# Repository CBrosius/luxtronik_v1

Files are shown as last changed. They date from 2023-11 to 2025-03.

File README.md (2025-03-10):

# luxtronik_v1 for Home Assistant
Luxtronik_v1 ESPHome External Component

# English version
This is a ESPHome ExternalComponent, that is able to read values from a Alpha Innotec Luxtronic_v1 Heatpump via Serial Connection (RS232)
and send the values to Homeassistant via Homeassistant-API or to other Smarthome Systems via MQTT

HowTo:
1. Edit luxtronik_v1.yaml according to your needs
3. Compile and Upload to your Sensor

# German Version
Mit einem ESP wird eine serielle Verbindung zur Luxtronik v1 Wärmepumpensteuerung hergestellt, es werden Werte ausgelesen und über die ESPHOME API für Home Assistant oder über MQTT für andere Smarthome Systeme bereitgestellt.

## Voraussetzungen

### Software
- Python [Anleitung](https://esphome.io/guides/installing_esphome)
- ESPHome Installation --> [download](https://esphome.io/)

### Hardware
- ESP (empfohlen ESP32)
- MAX3232-Modul
- serielles Kabel
- Sub-D9 Stecker männlich

## Serielle Verbindung
Die größte Hürde in diesem Projekt stellt die serielle Verbindung von der Luxtronik v1 zum ESP dar. Dieser Schritt wird die meiste Zeit in der Umsetzung erfordern.
Die Luxtronik verwendet 5V Pegel, während der ESP 3,3V Pegel verwendet, daher braucht es das MAX3232-Modul. Von allen möglichen Belegungen bei einem seriellen Kabel funktioniert letztlich nur eine, hier RX, TX und Ground/GND/Erde.

### ESP an MAX3232
Eine direkte Verbindung des ESP mit der Luxtronik v1 ist wegen der unterschiedlichen Spannungen nicht erfolgreich. Daher werden die PINs aus der ESP-Konfiguration mit dem MAX3232 verbunden. 

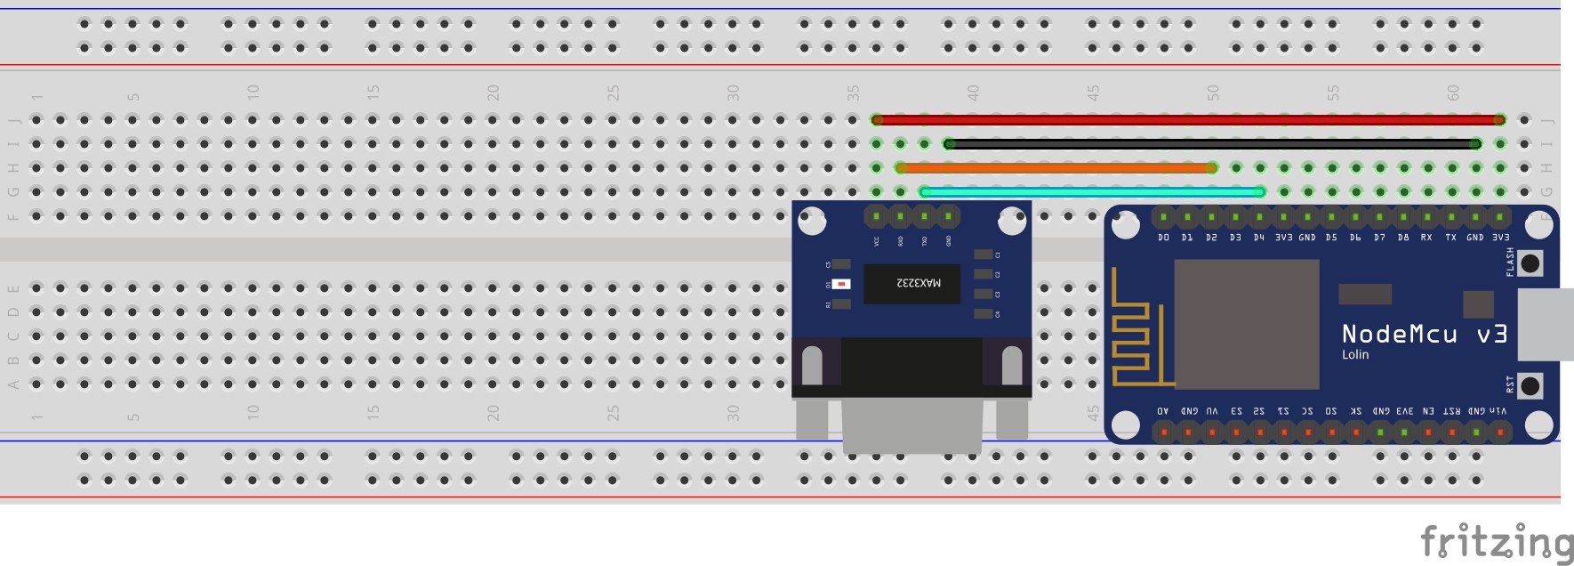
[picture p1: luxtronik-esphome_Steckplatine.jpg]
luxtronik-esphome_Steckplatine

#### D1 Mini
- ESP PIN D5 an MAX3232 RX
- ESP PIN D6 an MAX3232 TX
- ESP 3,3V an MAX3232 VCC
- ESP G an MAX3232 GND

#### ESP32
- ESP 3,3V an MAX3232 VCC
- ESP GND an MAX3232 GND
- ESP PIN RX2 (GPIO16) an MAX3232 RX 
- ESP PIN TX2 (GPIO17) an MAX3232 TX

### Serielles Kabel
Das serielle Kabel muss an der Luxtronik Platine angeschlossen werden. Dort gibt es einen männlichen Steckeranschluss (male), entsprechend muss das Kabel hier Buchsen (female) haben. Das MAX3232-Modul hat einen weiblichen Sub-D9 Buchsenanschluss (female), entsprechend braucht das Kabel hier einen männlichen Stecker (male). Kurz das Kabel braucht an einem Ende einen männlichen/male und am anderen Ende einen weiblichen/female Sub-D9 Stecker. Solche Kabel mit richtiger Belegung sind schwer zu finden, daher basteln wir uns ein solches Kabel selbst.

**Hinweis** Kommt keine serielle Verbindung zu stande, empfiehlt es sich an einer Seite RX und TX zu testweise zu tauschen.

#### Allgemeine RS232 Belegung
Das serielle Kabel muss wie folgt belegt sein:
- Pin 2 = RX
- Pin 3 = TX
- Pin 5 = GND / Erde

Beim Blick auf den Stecker bzw. die Buchse sind die Pins bei Buchse und Stecker an unterschiedlichen Stellen. Bei der Buchse sind die Pins 1- 5 die obere/breite Reihe von links nach rechts, beim Stecker von rechts nach links.

**Hinweis** Einen Genderchanger - also ein Zwischenstecker, der z.B. aus einer weiblichen Buchse einen männlichen Stecker macht - setzt man ein, wenn man z.B. nur zwei weibliche Stecker zur Verfügung hat. Dieser Genderchanger tauscht üblicherweise RX & TX. Wenn du einen Genderchanger einsetzt, musst du das bei der Belegung des Kabels beachten (und TX/RX tauschen, damit dann trotzdem 1:1 herauskommt).

#### Variante lötfreies Kabel
Die vorhandenen seriellen Kabel habe oft sehr dünne Litzen und sind entsprechend sensibel, was Zugbelastungen angeht. Möglicherweise möchtest du den ESP einige Meter entfernt von der Wärmepumpe betreiben, weil dort der WLAN-Empfang besser ist und brauchst daher eine entsprechend langes serielles Kabel.
Der Vorteil dieser Variante ist, dass als Kabel "Klingeldraht" verwendet werden kann und nicht gelötet werden muss.
Materialliste:
- dreiadriges Kabel in gewünschter Länge
- Sub-D9-Stecker lötfrei [Internetsuche](https://www.google.com/search?q=breakout+db9+connector+male)
- Sub-D9-Buchse lötfrei [Internetsuche](https://www.google.com/search?q=breakout+db9+connector+female)

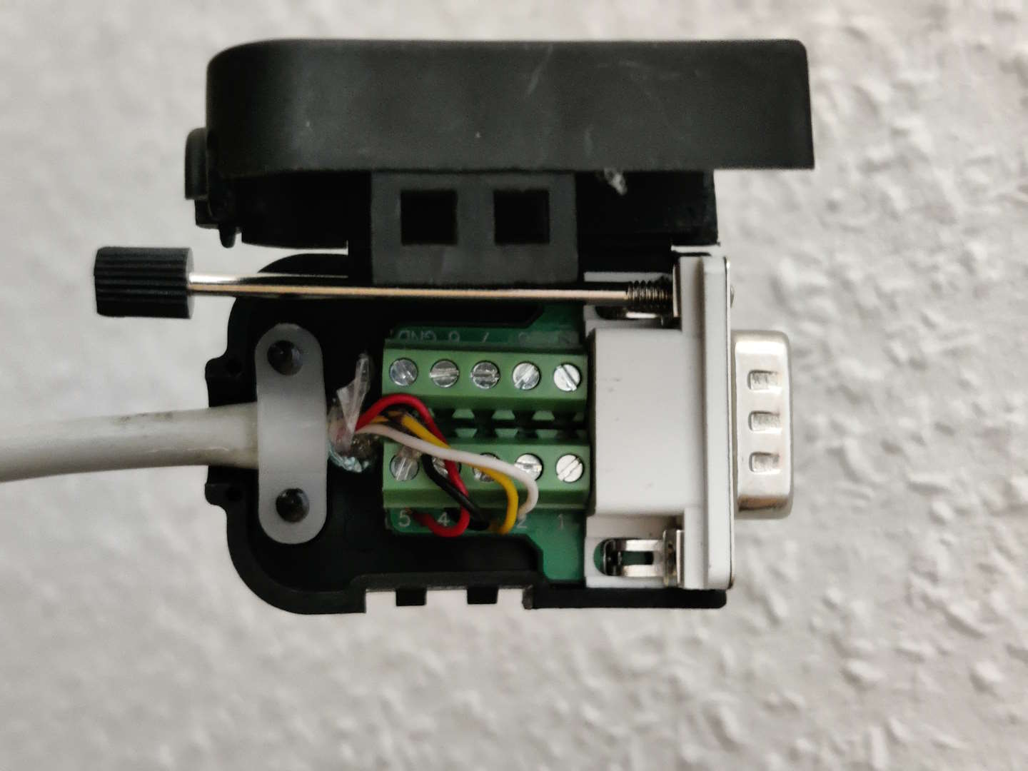
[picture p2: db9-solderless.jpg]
Db9-Lötfrei


#### Variante Cisco Konsolkabel
Ausgangspunkt ist ein Cisco Konsolkabel Sub-D9 auf RJ45, wie es für die Konfiguration von Netzwerkkomponenten des Herstellers zum Einsatz kommt - das ist kein MUSS, es funktioniert auch mit jedem beliebigen anderen Kabel.
Vom Sub-D9-Stecker werden von nur die PINs ??5 (RX), 6 (TX) und 4 (GND) benötigt. Diese haben folgende Kabelfarben:
- SubD9-PIN2, TX = rot
- SubD9-PIN3, RX = grün
- SubD9-PIN4, GND = gelb (auch PIN5 ist GND = orange) ??müsste es nicht PIN5/orange sein?

siehe auch: [hier](https://www.cable-tester.com/rj45-rs232-console-cable-pin-out/)
Schneide den RJ45-Stecker ab und löte den separten, männlichen Sub-D9-Stecker wie folgt an:
- grünes Kabel an SubD9-PIN 2 (TX)
- rotes Kabel an SubD9-PIN 3 (RX)
- gelbes Kabel an SubD9-PIN 5 (GND)

Info: Belegung von [Sub-D9](https://www.cable-tester.com/rs232-pin-out/).
### Luxtronik v1 Wartungszugang freischalten
An deiner Wärmepumpe gehe unter *Einstellungen, Datenzugang* dort die PIN 9445 für den Kundendienstzugang eingeben und bestätigen. Es passiert erstmal nix, es sind jetzt aber weitere Menüs erreichbar. Jetzt unter *Einstellungen, Diagnose* Standard auswählen. Damit ist die serielle Schnittstelle freigegeben. 

### secrets.yaml anlegen
Du brauchst eine Datei secrets.yaml in der du insbesondere die Werte für das WLAN einträgst:
```
# Your Wi-Fi SSID and password
wifi_ssid: "<SSID>"
wifi_password: "<WPA-Key>"
```
Wenn du die Home Assistant für die Erstellung von ESPHOME verwendest, dann hast du wahrscheinlich schon eine passende secrets.yaml.

Alle anderen Werte solltest du nur ändern, wenn du weißt, was du tust.

### ESPHome

#### Home Assistant Add-on 
Sofern noch nicht geschehen installierst du das Add-on "ESPHOME" (Einstellungen, Add-ons, Add-on-Store).

Wechsel in die "Benutzeroberfläche" von ESPHOME (z.B. über Einstellungen, Add-ons, ESPHOME, Benutzeroberfläche öffnen). Dort erscheint nun der "luxtronik-v1-esp32". Bei der erstmaligen Installation muss du ihn per Micro-USB an den PC anschließen und einen geeigneten Browser verwenden, um den Scetch auf den ESP zu laden. Weitere Updates können via WLAN erfolgen.

#### Windows
ESPHome ist eine Konsolenanwendung (unter Linux wie unter Windows).
Du kopierst alle Dateien des Projektes und deine secrets.yaml in das Hauptverzeichnis von esphome unter Windows standardmäßig c:\Users\\deinName\\.

Hinweis: Weitere Informationen findest du unter [esphome.io](https://esphome.io/guides/getting_started_command_line)

Stelle eine serielle Verbindung des ESP zum PC her. Das geht am einfachsten mit einem NodeMCU-Board, in diesem Fall schließe den ESP per Micro-USB-Kabel an deinen PC an. Es wird ein serieller Port am PC erzeugt (COM-Port, z.B. COM3).

Öffne eine Konsole, unter Windows öffne "command" und gib `esphome run luxtronik_v1-esp32.yaml` ein. Jetzt wird der Scetch compiliert, beim ersten mal dauert das ein paar Minuten.
Am Ende musst du auswählen, wie die Binärdatei auf den ESP kommt. Beim ersten Durchlauf musst du die serielle Verbindung nutzen, weitere Änderungen kannst du "OTA" (over the air) über das WLAN auf den ESP bringen, wenn dieser online ist.

#### WebInterface
Du kannst das WebInterface des ESP aufrufen und wirst die Werte der Luxtronik sehen können. 
Die IP-Adresse findest in deinem Router/DHCP-Server oder direkt im LOG des ESPHome-Devices.

## weitere Quellen
- https://wiki.fhem.de/wiki/Luxtronik_1_in_FHEM
- https://homematic-forum.de/forum/viewtopic.php?t=38814 
- https://knx-user-forum.de/forum/%C3%B6ffentlicher-bereich/knx-eib-forum/38901-%E2%88%9A-alpha-innotec-luxtronic-serielle-verbindung 
- http://www.hoerndlein.de/cms/index.php/openhab/8-einbindung-der-luxtronik-1-in-openhab
- https://bitbucket.org/tobylorenz/ait_luxtronik/src/master/
- https://www.haustechnikdialog.de/Forum/t/82258/Alpha-InnoTec-Anschluss-am-PC-klappt-nicht?page=23

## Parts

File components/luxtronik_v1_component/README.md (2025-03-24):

```yaml
# example configuration:

esphome:
  name: luxtronik-test
  friendly_name: luxtronik-test

esp32:
  board: esp32dev
  framework:
    type: esp-idf

wifi:
  ssid: !secret wifi_ssid
  password: !secret wifi_password
  fast_connect: True

# Enable logging
logger:
  # disable serial loggin
  baud_rate: 0

web_server:

api:

ota:
  platform: esphome

uart:
  id: uart_bus
  rx_pin: GPIO2
  tx_pin: GPIO4
  baud_rate: 57600
  data_bits: 8
  parity: NONE
  stop_bits: 1
#  debug:
#    direction: BOTH
#    dummy_receiver: false

external_components:
  - source:
      type: git
      url: https://github.com/cbrosius/luxtronik-v1-component
      ref: Input-sensors
    components: [ luxtronik_v1_component ]
    refresh: 0s

luxtronik_v1_component:
  id: luxtronik_v1_component_1
  temperatur_vorlauf:
    name: "Temperatur Vorlauf"
    id: temperatur_vorlauf
  temperatur_ruecklauf:
    name: "Temperatur Rücklauf"
    id: temperatur_ruecklauf
  temperatur_ruecklauf_soll:
    name: "Temperatur Rücklauf Soll"
    id: temperatur_ruecklauf_soll
  temperatur_heissgas:
    name: "Temperatur Heissgas"
    id: temperatur_heissgas
  temperatur_aussen:
    name: "Temperatur Aussen"
    id: temperatur_aussen
  temperatur_brauchwasser:
    name: "Temperatur Brauchwasser"
    id: temperatur_brauchwasser
  temperatur_brauchwasser_soll:
    name: "Temperatur Brauchwasser Soll"
    id: temperatur_brauchwasser_soll
  temperatur_waermequelle_eingang:
    name: "Temperatur Wärmequelle Eingang"
    id: temperatur_waermequelle_eingang
  temperatur_kaeltekreis:
    name: "Temperatur Kältekreis"
    id: temperatur_kaeltekreis
  temperatur_mischkreis1_vorlauf:
    name: "Temperatur Mischkreis1 Vorlauf"
    id: temperatur_mischkreis1_vorlauf
  temperatur_mischkreis1_vorlauf_soll:
    name: "Temperatur Mischkreis1 Vorlauf Soll"
    id: temperatur_mischkreis1_vorlauf_soll
  temperatur_raumstation:
    name: "Temperatur Raumstation"
    id: temperatur_raumstation
  eingang_abtau_soledruck_durchfluss:
    name: "Eingang Abtau Soledruck Durchfluss"
    id: eingang_abtau_soledruck_durchfluss
  eingang_sperrzeit_evu:
    name: "Eingang Sperrzeit EVU"
    id: eingang_sperrzeit_evu
  eingang_hochdruckpressostat:
    name: "Eingang Hochdruckpressostat"
    id: eingang_hochdruckpressostat
  eingang_motorschutz:
    name: "Eingang Motorschutz"
    id: eingang_motorschutz
  eingang_niederdruckpressostat:
    name: "Eingang Niederdruckpressostat"
    id: eingang_niederdruckpressostat
  eingang_fremdstromanode:
    name: "Eingang Fremdstromanode"
    id: eingang_fremdstromanode
  # Output sensors
  ausgang_abtauventil:
    name: "Ausgang Abtauventil"
    id: ausgang_abtauventil
  ausgang_brauchwasserpumpe:
    name: "Ausgang Brauchwasserpumpe"
    id: ausgang_brauchwasserpumpe
  ausgang_fussbodenheizungspumpe:
    name: "Ausgang Fußbodenheizungspumpe"
    id: ausgang_fussbodenheizungspumpe
  ausgang_heizungspumpe:
    name: "Ausgang Heizungspumpe"
    id: ausgang_heizungspumpe
  ausgang_mischer_1_auf:
    name: "Ausgang Mischer 1 Auf"
    id: ausgang_mischer_1_auf
  ausgang_mischer_1_zu:
    name: "Ausgang Mischer 1 Zu"
    id: ausgang_mischer_1_zu
  ausgang_ventilator_waermepumpe:
    name: "Ausgang Ventilator Wärmepumpe"
    id: ausgang_ventilator_waermepumpe
  ausgang_ventilator_brunnen:
    name: "Ausgang Ventilator Brunnen"
    id: ausgang_ventilator_brunnen
  ausgang_verdichter_1:
    name: "Ausgang Verdichter 1"
    id: ausgang_verdichter_1
  ausgang_verdichter_2:
    name: "Ausgang Verdichter 2"
    id: ausgang_verdichter_2
  ausgang_zirkulationspumpe:
    name: "Ausgang Zirkulationspumpe"
    id: ausgang_zirkulationspumpe
  ausgang_zweiter_waermeerzeuger:
    name: "Ausgang Zweiter Wärmeerzeuger"
    id: ausgang_zweiter_waermeerzeuger
  ausgang_zweiter_waermeerzeuger_stoerung:
    name: "Ausgang Zweiter Wärmeerzeuger Störung"
    id: ausgang_zweiter_waermeerzeuger_stoerung
  modus_heizung:
    name: "Modus Heizung"
    id: modus_heizung
  modus_heizung_numerisch:
    name: "Modus Heizung Numerisch"
    id: modus_heizung_numerisch
  modus_warmwasser:
    name: "Modus Warmwasser"
    id: modus_warmwasser
  modus_warmwasser_numerisch:
    name: "Modus Warmwasser Numerisch"
    id: modus_warmwasser_numerisch
  # Status sensors
  status_anlagentyp:
    name: "Status Anlagentyp"
    id: status_anlagentyp
  status_softwareversion:
    name: "Status Softwareversion"
    id: status_softwareversion
  status_bivalenzstufe:
    name: "Status Bivalenzstufe"
    id: status_bivalenzstufe
  status_betriebszustand:
    name: "Status Betriebszustand"
    id: status_betriebszustand
  status_betriebszustand_numerisch:
    name: "Status Betriebszustand Numerisch"
    id: status_betriebszustand_numerisch
  status_letzter_start:
    name: "Status Letzter Start"
    id: status_letzter_start
  # Fehler sensors
  error0_zeitpunkt:
    name: "Error0 Zeitpunkt"
    id: error0_zeitpunkt
  error0_fehlercode:
    name: "Error0 Fehlercode"
    id: error0_fehlercode
  error0_fehlerbeschreibung:
    name: "Error0 Fehlerbeschreibung"
    id: error0_fehlerbeschreibung
  error1_zeitpunkt:
    name: "Error1 Zeitpunkt"
    id: error1_zeitpunkt
  error1_fehlercode:
    name: "Error1 Fehlercode"
    id: error1_fehlercode
  error1_fehlerbeschreibung:
    name: "Error1 Fehlerbeschreibung"
    id: error1_fehlerbeschreibung
  error2_zeitpunkt:
    name: "Error2 Zeitpunkt"
    id: error2_zeitpunkt
  error2_fehlercode:
    name: "Error2 Fehlercode"
    id: error2_fehlercode
  error2_fehlerbeschreibung:
    name: "Error2 Fehlerbeschreibung"
    id: error2_fehlerbeschreibung
  error3_zeitpunkt:
    name: "Error3 Zeitpunkt"
    id: error3_zeitpunkt
  error3_fehlercode:
    name: "Error3 Fehlercode"
    id: error3_fehlercode
  error3_fehlerbeschreibung:
    name: "Error3 Fehlerbeschreibung"
    id: error3_fehlerbeschreibung
  error4_zeitpunkt:
    name: "Error4 Zeitpunkt"
    id: error4_zeitpunkt
  error4_fehlercode:
    name: "Error4 Fehlercode"
    id: error4_fehlercode
  error4_fehlerbeschreibung:
    name: "Error4 Fehlerbeschreibung"
    id: error4_fehlerbeschreibung
  # Betriebsstunden sensors
  betriebsstunden_verdichter_1:
    name: "Betriebsstunden Verdichter 1"
    id: betriebsstunden_verdichter_1
  impulse_verdichter_1:
    name: "Impulse Verdichter 1"
    id: impulse_verdichter_1
  durchschnittliche_einschaltdauer_verdichter_1:
    name: "Durchschnittliche Einschaltdauer Verdichter 1"
    id: durchschnittliche_einschaltdauer_verdichter_1
  betriebsstunden_verdichter_2:
    name: "Betriebsstunden Verdichter 2"  
    id: betriebsstunden_verdichter_2
  impulse_verdichter_2:
    name: "Impulse Verdichter 2"
    id: impulse_verdichter_2
  durchschnittliche_einschaltdauer_verdichter_2:
    name: "Durchschnittliche Einschaltdauer Verdichter 2"
    id: durchschnittliche_einschaltdauer_verdichter_2
  betriebsstunden_zweiter_waermeerzeuger_1:
    name: "Betriebsstunden Zweiter Wärmeerzeuger 1"
    id: betriebsstunden_zweiter_waermeerzeuger_1
  betriebsstunden_zweiter_waermeerzeuger_2:
    name: "Betriebsstunden Zweiter Wärmeerzeuger 2"
    id: betriebsstunden_zweiter_waermeerzeuger_2
  betriebsstunden_waermepumpe:
    name: "Betriebsstunden Wärmepumpe"
    id: betriebsstunden_waermepumpe

button:
  - platform: template
    name: " UART prüfen"
    id: check_uart
    on_press:
      then:
        - uart.write:
            data: "\r\n"
  - platform: template
    name: " Werte manuell abfragen"
    id: ask_for_values
    on_press:
      then:
        - uart.write:
            data: "1100\r\n"
```

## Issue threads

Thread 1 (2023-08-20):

Compiler Errors main.cpp:32

optimismus, 2023-08-20:
Hi, I really want to use ESP32 to read the data from AlphaInnotec and push it via MQTT to homeassistant.
This error is shown, when I compile the yaml:
`In file included from src/main.cpp:32:
src/luxtronik_v1_sensor.h:18:3: error: 'Sensor' does not name a type; did you mean 'gens'?
   Sensor *temp_VL           = new Sensor();  // Temperatur Vorlauf  -> 1100/2
   ^~~~~~
   gens
src/luxtronik_v1_sensor.h:19:3: error: 'Sensor' does not name a type; did you mean 'gens'?
   Sensor *temp_RL           = new Sensor();  // Temperatur Rücklauf -> 1100/3
   ^~~~~~
   gens
src/luxtronik_v1_sensor.h:20:3: error: 'Sensor' does not name a type; did you mean 'gens'?
   Sensor *temp_RL_Soll      = new Sensor();  // Temperatur Rücklauf-Soll -> 1100/4
   ^~~~~~
   gens
src/luxtronik_v1_sensor.h:21:3: error: 'Sensor' does not name a type; did you mean 'gens'?
   Sensor *temp_Heissgas     = new Sensor();  // 1100/5
   ^~~~~~
   gens
src/luxtronik_v1_sensor.h:22:3: error: 'Sensor' does not name a type; did you mean 'gens'?
   Sensor *temp_Aussen       = new Sensor();  // 1100/6
   ^~~~~~
   gens
src/luxtronik_v1_sensor.h:23:3: error: 'Sensor' does not name a type; did you mean 'gens'?
   Sensor *temp_BW           = new Sensor();  // 1100/7
   ^~~~~~
   gens
src/luxtronik_v1_sensor.h:24:3: error: 'Sensor' does not name a type; did you mean 'gens'?
   Sensor *temp_BW_Soll      = new Sensor();  // 1100/8
   ^~~~~~
   gens
src/luxtronik_v1_sensor.h:25:3: error: 'Sensor' does not name a type; did you mean 'gens'?
   Sensor *temp_WQ_Ein       = new Sensor();  // 1100/9
   ^~~~~~
   gens
src/luxtronik_v1_sensor.h:26:3: error: 'Sensor' does not name a type; did you mean 'gens'?
   Sensor *temp_Kaeltekreis  = new Sensor();  // 1100/10
   ^~~~~~
   gens
src/luxtronik_v1_sensor.h:27:3: error: 'Sensor' does not name a type; did you mean 'gens'?
   Sensor *temp_MK1_Vorl     = new Sensor();  // 1100/11
   ^~~~~~
   gens
src/luxtronik_v1_sensor.h:28:3: error: 'Sensor' does not name a type; did you mean 'gens'?
   Sensor *temp_MK1VL_Soll   = new Sensor();  // 1100/12
   ^~~~~~
   gens
src/luxtronik_v1_sensor.h:29:3: error: 'Sensor' does not name a type; did you mean 'gens'?
   Sensor *temp_Raumstat     = new Sensor();  // 1100/13
   ^~~~~~
   gens
src/luxtronik_v1_sensor.h:31:3: error: 'Sensor' does not name a type; did you mean 'gens'?
   Sensor *ein_Abtau_Soledruck_Durchfluss  = new Sensor();  // 1200/2
   ^~~~~~
   gens
src/luxtronik_v1_sensor.h:32:3: error: 'Sensor' does not name a type; did you mean 'gens'?
   Sensor *ein_Sperrzeit_EVU               = new Sensor();  // 1200/3
   ^~~~~~
   gens
src/luxtronik_v1_sensor.h:33:3: error: 'Sensor' does not name a type; did you mean 'gens'?
   Sensor *ein_Hochdruckpressostat         = new Sensor();  // 1200/4
   ^~~~~~
   gens
src/luxtronik_v1_sensor.h:34:3: error: 'Sensor' does not name a type; did you mean 'gens'?
   Sensor *ein_Motorschutz                 = new Sensor();  // 1200/5
   ^~~~~~
   gens
src/luxtronik_v1_sensor.h:35:3: error: 'Sensor' does not name a type; did you mean 'gens'?
   Sensor *ein_Niederdruckpressostat       = new Sensor();  // 1200/6
   ^~~~~~
   gens
src/luxtronik_v1_sensor.h:36:3: error: 'Sensor' does not name a type; did you mean 'gens'?
   Sensor *ein_Fremdstromanode             = new Sensor();  // 1200/7
   ^~~~~~
   gens
src/luxtronik_v1_sensor.h:38:3: error: 'Sensor' does not name a type; did you mean 'gens'?
   Sensor *aus_ATV             = new Sensor();  // 1300/2
   ^~~~~~
   gens
src/luxtronik_v1_sensor.h:39:3: error: 'Sensor' does not name a type; did you mean 'gens'?
   Sensor *aus_BWP             = new Sensor();  // 1300/3
   ^~~~~~
   gens
src/luxtronik_v1_sensor.h:40:3: error: 'Sensor' does not name a type; did you mean 'gens'?
   Sensor *aus_FBHP            = new Sensor();  // 1300/4
   ^~~~~~
   gens
src/luxtronik_v1_sensor.h:41:3: error: 'Sensor' does not name a type; did you mean 'gens'?
   Sensor *aus_HZP             = new Sensor();  // 1300/5
   ^~~~~~
   gens
src/luxtronik_v1_sensor.h:42:3: error: 'Sensor' does not name a type; did you mean 'gens'?
   Sensor *aus_Mischer_1_Auf   = new Sensor();  // 1300/6
   ^~~~~~
   gens
src/luxtronik_v1_sensor.h:43:3: error: 'Sensor' does not name a type; did you mean 'gens'?
   Sensor *aus_Mischer_1_Zu    = new Sensor();  // 1300/7
   ^~~~~~
   gens
src/luxtronik_v1_sensor.h:44:3: error: 'Sensor' does not name a type; did you mean 'gens'?
   Sensor *aus_VentWP          = new Sensor();  // 1300/8
   ^~~~~~
   gens
src/luxtronik_v1_sensor.h:45:3: error: 'Sensor' does not name a type; did you mean 'gens'?
   Sensor *aus_VentBrunnen     = new Sensor();  // 1300/9
   ^~~~~~
   gens
src/luxtronik_v1_sensor.h:46:3: error: 'Sensor' does not name a type; did you mean 'gens'?
   Sensor *aus_Verdichter_1    = new Sensor();  // 1300/10
   ^~~~~~
   gens
src/luxtronik_v1_sensor.h:47:3: error: 'Sensor' does not name a type; did you mean 'gens'?
   Sensor *aus_Verdichter_2    = new Sensor();  // 1300/11
   ^~~~~~
   gens
src/luxtronik_v1_sensor.h:48:3: error: 'Sensor' does not name a type; did you mean 'gens'?
   Sensor *aus_ZPumpe          = new Sensor();  // 1300/12
   ^~~~~~
   gens
src/luxtronik_v1_sensor.h:49:3: error: 'Sensor' does not name a type; did you mean 'gens'?
   Sensor *aus_ZWE             = new Sensor();  // 1300/13
   ^~~~~~
   gens
Compiling .pioenvs\luxtronik\libe88\ESPAsyncWebServer-esphome\AsyncEventSource.cpp.o
src/luxtronik_v1_sensor.h:50:3: error: 'Sensor' does not name a type; did you mean 'gens'?
   Sensor *aus_ZWE_Stoerung    = new Sensor();  // 1300/14
   ^~~~~~
   gens
src/luxtronik_v1_sensor.h: In member function 'void esphome::luxtronik_v1_sensor::parse_cmd_(std::__cxx11::string)':
src/luxtronik_v1_sensor.h:120:9: error: 'temp_VL' was not declared in this scope
         temp_VL->publish_state(GetFloatTemp(tmp_VL));
         ^~~~~~~
src/luxtronik_v1_sensor.h:120:9: note: suggested alternative: 'tmp_VL'
         temp_VL->publish_state(GetFloatTemp(tmp_VL));
         ^~~~~~~
         tmp_VL
src/luxtronik_v1_sensor.h:126:9: error: 'temp_RL' was not declared in this scope
         temp_RL->publish_state(GetFloatTemp(tmp_RL));
         ^~~~~~~
src/luxtronik_v1_sensor.h:126:9: note: suggested alternative: 'tmp_RL'
         temp_RL->publish_state(GetFloatTemp(tmp_RL));
         ^~~~~~~
         tmp_RL
src/luxtronik_v1_sensor.h:132:9: error: 'temp_RL_Soll' was not declared in this scope
         temp_RL_Soll->publish_state(GetFloatTemp(tmp_RL_Soll));
         ^~~~~~~~~~~~
src/luxtronik_v1_sensor.h:132:9: note: suggested alternative: 'tmp_RL_Soll'
         temp_RL_Soll->publish_state(GetFloatTemp(tmp_RL_Soll));
         ^~~~~~~~~~~~
         tmp_RL_Soll
src/luxtronik_v1_sensor.h:138:9: error: 'temp_Heissgas' was not declared in this scope
         temp_Heissgas->publish_state(GetFloatTemp(tmp_Heissgas));
         ^~~~~~~~~~~~~
src/luxtronik_v1_sensor.h:138:9: note: suggested alternative: 'tmp_Heissgas'
         temp_Heissgas->publish_state(GetFloatTemp(tmp_Heissgas));
         ^~~~~~~~~~~~~
         tmp_Heissgas
src/luxtronik_v1_sensor.h:144:9: error: 'temp_Aussen' was not declared in this scope
         temp_Aussen->publish_state(GetFloatTemp(tmp_Aussen));
         ^~~~~~~~~~~
src/luxtronik_v1_sensor.h:144:9: note: suggested alternative: 'tmp_Aussen'
         temp_Aussen->publish_state(GetFloatTemp(tmp_Aussen));
         ^~~~~~~~~~~
         tmp_Aussen
src/luxtronik_v1_sensor.h:150:9: error: 'temp_BW' was not declared in this scope
         temp_BW->publish_state(GetFloatTemp(tmp_BW));
         ^~~~~~~
src/luxtronik_v1_sensor.h:150:9: note: suggested alternative: 'tmp_BW'
         temp_BW->publish_state(GetFloatTemp(tmp_BW));
         ^~~~~~~
         tmp_BW
src/luxtronik_v1_sensor.h:156:9: error: 'temp_BW_Soll' was not declared in this scope
         temp_BW_Soll->publish_state(GetFloatTemp(tmp_BW_Soll));
         ^~~~~~~~~~~~
src/luxtronik_v1_sensor.h:156:9: note: suggested alternative: 'tmp_BW_Soll'
         temp_BW_Soll->publish_state(GetFloatTemp(tmp_BW_Soll));
         ^~~~~~~~~~~~
         tmp_BW_Soll
src/luxtronik_v1_sensor.h:162:9: error: 'temp_WQ_Ein' was not declared in this scope
         temp_WQ_Ein->publish_state(GetFloatTemp(tmp_WQ_Ein));
         ^~~~~~~~~~~
src/luxtronik_v1_sensor.h:162:9: note: suggested alternative: 'tmp_WQ_Ein'
         temp_WQ_Ein->publish_state(GetFloatTemp(tmp_WQ_Ein));
         ^~~~~~~~~~~
         tmp_WQ_Ein
src/luxtronik_v1_sensor.h:168:9: error: 'temp_Kaeltekreis' was not declared in this scope
         temp_Kaeltekreis->publish_state(GetFloatTemp(tmp_Kaeltekreis));
         ^~~~~~~~~~~~~~~~
src/luxtronik_v1_sensor.h:168:9: note: suggested alternative: 'tmp_Kaeltekreis'
         temp_Kaeltekreis->publish_state(GetFloatTemp(tmp_Kaeltekreis));
         ^~~~~~~~~~~~~~~~
         tmp_Kaeltekreis
src/luxtronik_v1_sensor.h:174:9: error: 'temp_MK1_Vorl' was not declared in this scope
         temp_MK1_Vorl->publish_state(GetFloatTemp(tmp_MK1_Vorl));
         ^~~~~~~~~~~~~
src/luxtronik_v1_sensor.h:174:9: note: suggested alternative: 'tmp_MK1_Vorl'
         temp_MK1_Vorl->publish_state(GetFloatTemp(tmp_MK1_Vorl));
         ^~~~~~~~~~~~~
         tmp_MK1_Vorl
src/luxtronik_v1_sensor.h:180:9: error: 'temp_MK1VL_Soll' was not declared in this scope
         temp_MK1VL_Soll->publish_state(GetFloatTemp(tmp_MK1VL_Soll));
         ^~~~~~~~~~~~~~~
src/luxtronik_v1_sensor.h:180:9: note: suggested alternative: 'tmp_MK1VL_Soll'
         temp_MK1VL_Soll->publish_state(GetFloatTemp(tmp_MK1VL_Soll));
         ^~~~~~~~~~~~~~~
         tmp_MK1VL_Soll
src/luxtronik_v1_sensor.h:186:9: error: 'temp_Raumstat' was not declared in this scope
         temp_Raumstat->publish_state(GetFloatTemp(tmp_Raumstat));
         ^~~~~~~~~~~~~
src/luxtronik_v1_sensor.h:186:9: note: suggested alternative: 'tmp_Raumstat'
         temp_Raumstat->publish_state(GetFloatTemp(tmp_Raumstat));
         ^~~~~~~~~~~~~
         tmp_Raumstat
src/luxtronik_v1_sensor.h:203:9: error: 'ein_Abtau_Soledruck_Durchfluss' was not declared in this scope
         ein_Abtau_Soledruck_Durchfluss->publish_state(GetInputOutputState(tmp_in));
         ^~~~~~~~~~~~~~~~~~~~~~~~~~~~~~
Archiving .pioenvs\luxtronik\lib39f\libAsyncTCP-esphome.a
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
CBrosius, 2023-08-20:
Hi Axel, this is exactly what I am doing. I use a ESP8266 Wemos D1 Mini in my YAML-Code.
Did you change this to your ESP32-Board?

Kind regards,
Christian...

optimismus, 2023-08-21:
Hi Christian,
I tried to use an nodemcu ESP32. This is, how I edited the yaml file:
`esphome:
  name: luxtronik
  includes:
    - luxtronik_v1_sensor.h

esp32:
  board: nodemcu-32s
  framework:
    type: arduino

# Enable logging
logger:

# Enable Home Assistant API
api:
  password: ""

ota:
  password: ""

wifi:
  ssid: "mywifi"
  password: "wpa-secret"

  # Enable fallback hotspot (captive portal) in case wifi connection fails
  ap:
    ssid: "Luxtronik Fallback Hotspot"
    password: "secret"

captive_portal:

web_server:
  port: 80

mqtt:
  broker: 192.168.1.1
  # Optional variables:
  discovery: true

# Schnittstellen-Parameter: 57600, 8, N, 1
uart:
  baud_rate: 57600
  rx_pin: GPIO3
  tx_pin: GPIO1
  # baud_rate (Required, int): The baud rate of the UART bus.
  # rx_pin (Optional, Pin): The pin to receive data on from the ESP’s perspective.
  # tx_pin (Optional, Pin): The pin to send data to from the ESP’s perspective.
  data_bits: 8
  #data_bits (Optional, int): The number of data bits used on the UART bus. Options: 5 to 8. Defaults to 8.
  #parity (Optional): The parity used on the UART bus. Options: NONE, EVEN, ODD. Defaults to NONE.
  parity: NONE
  #stop_bits (Optional, int): The number of stop bits to send. Options: 1, 2. Defaults to 1.
  stop_bits: 1
  # id (Optional, ID): Manually specify the ID for this UART hub if you need multiple UART hubs
  id: uart_bus

    `
But obviously that was wrong.
I put out an d1 mini and used that, it works, no compiler errors.

Closed 2023-08-21.

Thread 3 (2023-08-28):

esp32 compiling errors 'class esphome::luxtronik_v1_sensor' has no member named 'status_Anlagentyp'

optimismus, 2023-08-28:
I tried to use the esp32-example, but got compiler errors:

Compiling .pioenvs\luxtronik-v1-esp32\liba95\Update\Updater.cpp.o
luxtronik-v1-esp32.yaml: In lambda function:
luxtronik-v1-esp32.yaml:92:23: error: 'class esphome::luxtronik_v1_sensor' has no member named 'status_Anlagentyp'
luxtronik-v1-esp32.yaml:93:23: error: 'class esphome::luxtronik_v1_sensor' has no member named 'status_Softwareversion'; did you mean 'status_clear_error'?
luxtronik-v1-esp32.yaml:94:23: error: 'class esphome::luxtronik_v1_sensor' has no member named 'status_Bivalenzstufe'
luxtronik-v1-esp32.yaml:95:23: error: 'class esphome::luxtronik_v1_sensor' has no member named 'status_Betriebszustand'
luxtronik-v1-esp32.yaml:96:7: error: could not convert '{luxtronik_v1->esphome::luxtronik_v1_sensor::temp_VL, luxtronik_v1->esphome::luxtronik_v1_sensor::temp_RL, luxtronik_v1->esphome::luxtronik_v1_sensor::temp_RL_Soll, luxtronik_v1->esphome::luxtronik_v1_sensor::temp_Heissgas, luxtronik_v1->esphome::luxtronik_v1_sensor::temp_Aussen, luxtronik_v1->esphome::luxtronik_v1_sensor::temp_BW, luxtronik_v1->esphome::luxtronik_v1_sensor::temp_BW_Soll, luxtronik_v1->esphome::luxtronik_v1_sensor::temp_WQ_Ein, luxtronik_v1->esphome::luxtronik_v1_sensor::temp_Kaeltekreis, luxtronik_v1->esphome::luxtronik_v1_sensor::temp_MK1_Vorl, luxtronik_v1->esphome::luxtronik_v1_sensor::temp_MK1VL_Soll, luxtronik_v1->esphome::luxtronik_v1_sensor::temp_Raumstat, luxtronik_v1->esphome::luxtronik_v1_sensor::ein_Abtau_Soledruck_Durchfluss, luxtronik_v1->esphome::luxtronik_v1_sensor::ein_Sperrzeit_EVU, luxtronik_v1->esphome::luxtronik_v1_sensor::ein_Hochdruckpressostat, luxtronik_v1->esphome::luxtronik_v1_sensor::ein_Motorschutz, luxtronik_v1->esphome::luxtronik_v1_sensor::ein_Niederdruckpressostat, luxtronik_v1->esphome::luxtronik_v1_sensor::ein_Fremdstromanode, luxtronik_v1->esphome::luxtronik_v1_sensor::aus_ATV, luxtronik_v1->esphome::luxtronik_v1_sensor::aus_BWP, luxtronik_v1->esphome::luxtronik_v1_sensor::aus_FBHP, luxtronik_v1->esphome::luxtronik_v1_sensor::aus_HZP, luxtronik_v1->esphome::luxtronik_v1_sensor::aus_Mischer_1_Auf, luxtronik_v1->esphome::luxtronik_v1_sensor::aus_Mischer_1_Zu, luxtronik_v1->esphome::luxtronik_v1_sensor::aus_VentWP, luxtronik_v1->esphome::luxtronik_v1_sensor::aus_VentBrunnen, luxtronik_v1->esphome::luxtronik_v1_sensor::aus_Verdichter_1, luxtronik_v1->esphome::luxtronik_v1_sensor::aus_Verdichter_2, luxtronik_v1->esphome::luxtronik_v1_sensor::aus_ZPumpe, luxtronik_v1->esphome::luxtronik_v1_sensor::aus_ZWE, luxtronik_v1->esphome::luxtronik_v1_sensor::aus_ZWE_Stoerung, <expression error>, <expression error>, <expression error>, <expression error>}' from '<brace-enclosed initializer list>' to 'std::vector<esphome::sensor::Sensor*>'
Compiling .pioenvs\luxtronik-v1-esp32\libc20\ESPAsyncWebServer-esphome\AsyncEventSource.cpp.o
Archiving .pioenvs\luxtronik-v1-esp32\lib21b\libAsyncTCP-esphome.a
Compiling .pioenvs\luxtronik-v1-esp32\libc20\ESPAsyncWebServer-esphome\AsyncWebSocket.cpp.o
Compiling .pioenvs\luxtronik-v1-esp32\libc20\ESPAsyncWebServer-esphome\WebAuthentication.cpp.o
Compiling .pioenvs\luxtronik-v1-esp32\libc20\ESPAsyncWebServer-esphome\WebHandlers.cpp.o
Compiling .pioenvs\luxtronik-v1-esp32\libc20\ESPAsyncWebServer-esphome\WebRequest.cpp.o
Compiling .pioenvs\luxtronik-v1-esp32\libc20\ESPAsyncWebServer-esphome\WebResponses.cpp.o
Compiling .pioenvs\luxtronik-v1-esp32\libc20\ESPAsyncWebServer-esphome\WebServer.cpp.o
Compiling .pioenvs\luxtronik-v1-esp32\lib94e\ESPmDNS\ESPmDNS.cpp.o
*** [.pioenvs\luxtronik-v1-esp32\src\main.cpp.o] Error 1
============================================= [FAILED] Took 40.26 seconds =

CBrosius, 2023-08-30:
You are right, I forgot to add the 2 new attributes to the esp32.yaml.
They are included now. Does this fix your compile-errors?

optimismus, 2023-08-31:
Sorry: No.
I deleted the temporary folder under .eshome/build for esp32, but this ist the result (only the error part):
Compiling .pioenvs\luxtronik-v1-esp32\libc20\ESPAsyncWebServer-esphome\AsyncEventSource.cpp.o
luxtronik-v1-esp32.yaml: In lambda function:
luxtronik-v1-esp32.yaml:92:23: error: 'class esphome::luxtronik_v1_sensor' has no member named 'status_Anlagentyp'
luxtronik-v1-esp32.yaml:93:23: error: 'class esphome::luxtronik_v1_sensor' has no member named 'status_Softwareversion'; did you mean 'status_clear_error'?
luxtronik-v1-esp32.yaml:94:23: error: 'class esphome::luxtronik_v1_sensor' has no member named 'status_Bivalenzstufe'
luxtronik-v1-esp32.yaml:95:23: error: 'class esphome::luxtronik_v1_sensor' has no member named 'status_Betriebszustand'
luxtronik-v1-esp32.yaml:96:23: error: 'class esphome::luxtronik_v1_sensor' has no member named 'modus_Heizung'
luxtronik-v1-esp32.yaml:97:23: error: 'class esphome::luxtronik_v1_sensor' has no member named 'modus_Warmwasser'
luxtronik-v1-esp32.yaml:98:7: error: could not convert '{luxtronik_v1->esphome::luxtronik_v1_sensor::temp_VL, luxtronik_v1->esphome::luxtronik_v1_sensor::temp_RL, luxtronik_v1->esphome::luxtronik_v1_sensor::temp_RL_Soll, luxtronik_v1->esphome::luxtronik_v1_sensor::temp_Heissgas, luxtronik_v1->esphome::luxtronik_v1_sensor::temp_Aussen, luxtronik_v1->esphome::luxtronik_v1_sensor::temp_BW, luxtronik_v1->esphome::luxtronik_v1_sensor::temp_BW_Soll, luxtronik_v1->esphome::luxtronik_v1_sensor::temp_WQ_Ein, luxtronik_v1->esphome::luxtronik_v1_sensor::temp_Kaeltekreis, luxtronik_v1->esphome::luxtronik_v1_sensor::temp_MK1_Vorl, luxtronik_v1->esphome::luxtronik_v1_sensor::temp_MK1VL_Soll, luxtronik_v1->esphome::luxtronik_v1_sensor::temp_Raumstat, luxtronik_v1->esphome::luxtronik_v1_sensor::ein_Abtau_Soledruck_Durchfluss, luxtronik_v1->esphome::luxtronik_v1_sensor::ein_Sperrzeit_EVU, luxtronik_v1->esphome::luxtronik_v1_sensor::ein_Hochdruckpressostat, luxtronik_v1->esphome::luxtronik_v1_sensor::ein_Motorschutz, luxtronik_v1->esphome::luxtronik_v1_sensor::ein_Niederdruckpressostat, luxtronik_v1->esphome::luxtronik_v1_sensor::ein_Fremdstromanode, luxtronik_v1->esphome::luxtronik_v1_sensor::aus_ATV, luxtronik_v1->esphome::luxtronik_v1_sensor::aus_BWP, luxtronik_v1->esphome::luxtronik_v1_sensor::aus_FBHP, luxtronik_v1->esphome::luxtronik_v1_sensor::aus_HZP, luxtronik_v1->esphome::luxtronik_v1_sensor::aus_Mischer_1_Auf, luxtronik_v1->esphome::luxtronik_v1_sensor::aus_Mischer_1_Zu, luxtronik_v1->esphome::luxtronik_v1_sensor::aus_VentWP, luxtronik_v1->esphome::luxtronik_v1_sensor::aus_VentBrunnen, luxtronik_v1->esphome::luxtronik_v1_sensor::aus_Verdichter_1, luxtronik_v1->esphome::luxtronik_v1_sensor::aus_Verdichter_2, luxtronik_v1->esphome::luxtronik_v1_sensor::aus_ZPumpe, luxtronik_v1->esphome::luxtronik_v1_sensor::aus_ZWE, luxtronik_v1->esphome::luxtronik_v1_sensor::aus_ZWE_Stoerung, <expression error>, <expression error>, <expression error>, <expression error>, <expression error>, <expression error>}' from '<brace-enclosed initializer list>' to 'std::vector<esphome::sensor::Sensor*>'
Archiving .pioenvs\luxtronik-v1-esp32\lib21b\libAsyncTCP-esphome.a
Compiling .pioenvs\luxtronik-v1-esp32\libc20\ESPAsyncWebServer-esphome\AsyncWebSocket.cpp.o
Compiling .pioenvs\luxtronik-v1-esp32\libc20\ESPAsyncWebServer-esphome\WebAuthentication.cpp.o
Compiling .pioenvs\luxtronik-v1-esp32\libc20\ESPAsyncWebServer-esphome\WebHandlers.cpp.o
Compiling .pioenvs\luxtronik-v1-esp32\libc20\ESPAsyncWebServer-esphome\WebRequest.cpp.o
Compiling .pioenvs\luxtronik-v1-esp32\libc20\ESPAsyncWebServer-esphome\WebResponses.cpp.o
Compiling .pioenvs\luxtronik-v1-esp32\libc20\ESPAsyncWebServer-esphome\WebServer.cpp.o
*** [.pioenvs\luxtronik-v1-esp32\src\main.cpp.o] Error 1
============================================= [FAILED] Took 33.65 seconds =============================================
Seem to be the same error.

I attach an image of my board, just to be sure it is compatible with your config:

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

optimismus, 2023-09-03:
After deleting all temp dirs and recompiling it compiles successfully. Thanks a lot for your work.

Closed 2023-09-03.

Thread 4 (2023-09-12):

ESP doesn't show values

optimismus, 2023-09-12:
I used the luxtronik-v1-esp32.yaml with an esp32. After establishing the serial connection (verified with HTerm on Windows and LuxController) the request ("1100\r\n") is send, but no values are shown in the webinterface (values are "NA") nor the entities in HA are filled.

I send the codes manually with HTerm to Luxtronik (same serial cable) and got this as response:

```
1100<\r><\n>
1100;12;260;261;150;242;220;492;500;247;250;750;0;0<\r><\n>
1200<\r><\n>
1200;6;1;1;0;1;1;0<\r><\n>
1300<\r><\n>
1300;13;0;0;0;0;0;1;0;0;0;0;0;0;0<\r><\n>
1700<\r><\n>
1700;12;11; V2.33;1;5;25;8;23;9;49;16,0,0<\r><\n>
3405<\r><\n>
3405;1;4<\r><\n>
3505<\r><\n>
3505;1;0<\r><\n>
```
While this looks pretty as your values (in comment in luxtronik_v1_sensor.h) HTerm shows an echo of "1100", "1200" as you can see of the received output.

Closed 2023-09-16.

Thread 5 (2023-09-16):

WP_Modus_Warmwasser missing

optimismus, 2023-09-16:
I use the ESP32.yaml.
Although

`22:02:59 | [D] | [luxtronik_v1:417] | 3405 found -> Heizungsmodus
-- | -- | -- | --
22:02:59 | [D] | [luxtronik_v1:418] | R: 3405;1;4 - 0
22:02:59 | [D] | [sensor:094] | 'WP_Status_Betriebszustand': Sending state 4.00000  with 0 decimals of accuracy
22:02:59 | [D] | [luxtronik_v1:115] | S: 3505 - 0
22:02:59 | [D] | [luxtronik_v1:435] | 3505 found -> Warmwassermodus
22:02:59 | [D] | [luxtronik_v1:436] | R: 3505;1;0 - 0
22:02:59 | [D] | [sensor:094] | 'WP_Modus_Heizung': Sending state 0.00000  with 0 decimals of accuracy`

it is not shown and not an entity in Homeassistant.

CBrosius, 2023-09-17:
Sensor-Entry for WP_Modus_Warmwasser was missing. This is added, now.

Closed 2023-11-01.

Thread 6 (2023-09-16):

Softwareversion "NA"

optimismus, 2023-09-16:
I use the esp32.yaml.
Although in the log the software version is given by the heat pump:
"22:03:58 | [D] | [luxtronik_v1:356] | Softwareversion:  V2.33"

it is not shown in the webinterface nor in the HA entity.
I assume this ist caused by a leading blank sign at the beginning of the string:
"1700;12;11; **V2.33**;1;5;25;8;23;9;49;16,0,0"

CBrosius, 2023-09-17:
Yes the responding part in [luxtronik_v1_sensor.h](https://github.com/CBrosius/luxtronik_v1/blob/main/luxtronik_v1_sensor.h) (line 356) is not implemented. But I put it back in my todo-list until other things are working.
All other values are numbers, but the Version is a String. So this has to be implemented different.

CBrosius, 2023-11-01:
From now on I handle the software-version as a float with two digits.
So this issue should be fixed for now.

Closed 2023-11-01.

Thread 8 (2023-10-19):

"components should block"

optimismus, 2023-10-19:
This is inside my ESP logging:
`[20:34:41][D][luxtronik_v1:116]: S: 1200 - 0
[20:34:41][W][component:204]: Component <unknown> took a long time for an operation (0.14 s).
[20:34:41][W][component:205]: Components should block for at most 20-30ms.
[20:34:41][D][luxtronik_v1:212]: 1200 found -> Inputs`

I think the ESP need some time to work with the results?! May be there should be a little pause between the calls?

CBrosius, 2023-11-01:
Yes this is a warning, that is shown now by ESPHome since 2023.7.0
There is an issue (https://github.com/esphome/issues/issues/4717) in the esphome-git for this already open.

`And here, basically we have two choices:

The sensor requires a nudge to send back the value over the bus:
in update() we write the "update_me" command, we return
in loop() we read the response and publish the requested sensors as we receive them, if the sensor requires more command for the other server, we send the command after each read(). We need a local buffer to cover those responses. And state tracking
The sensor streams value:
in loop(): we read values and update local variables
in update(): we publish the values we have available.
Unfortunately this won't solve the case of eInk displays. There is no way current technology would refresh a screen in 30ms. That is an entirely different matter. In general with the stream approach you need to fall back to continuations. Anyone who has used JavaScript before Promise knows where that staircase will eventually lead.`

Maybe we can try to include some update() lines in the loop()-codepart.

cbrosius, 2025-03-10:
with the actual version I rewrote the parsing logic and got rid of mostly all blocking warnings.
so I will mark this issue as fixed

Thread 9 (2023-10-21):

Update to ESPHOME 2023.10 broke ESP32

optimismus, 2023-10-21:
After updating to ESPHOME 2023.10 inside of HA, the ESP32 stops working. It was still in the network (pingable), but doesn't even expose the webinterface nor connect via ESPHOME.

CBrosius, 2023-10-22:
I cannot reproduce this issue. Update to 2023.10 and 2023.10.1 went flawless on my side.

optimismus, 2023-10-23:
I reproduced the issue today: Is your ESP connected to heatpump? (my is)
Before:
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
after installing 2023.10.1 the luxtronik-v1-esp32.local is available in network:
>Ping wird ausgeführt für luxtronik-v1-esp32.local [192.168.178.51] mit 32 Bytes Daten:
>Antwort von 192.168.178.51: Bytes=32 Zeit=153ms TTL=255
>Antwort von 192.168.178.51: Bytes=32 Zeit=339ms TTL=255

but webserver (http://luxtronik-v1-esp32.local/) nor API calls are working:
>INFO ESPHome 2023.10.1
INFO Reading configuration /config/esphome/luxtronik-v1-esp32.yaml...
WARNING GPIO2 is a Strapping PIN and should be avoided.
Attaching external pullup/down resistors to strapping pins can cause unexpected failures.
See https://esphome.io/guides/faq.html#why-am-i-getting-a-warning-about-strapping-pins
INFO Starting log output from luxtronik-v1-esp32.local using esphome API
WARNING Can't connect to ESPHome API for luxtronik-v1-esp32.local: Error connecting to ('192.168.178.51', 6053): [Errno 111] Connect call failed ('192.168.178.51', 6053) (SocketAPIError)
INFO Trying to connect to luxtronik-v1-esp32.local in the background

I don't know, if there is a way to provide e.g. logs over serial connection.
To get the esp back to work, I have to connect it via USB to my computer and flash it via COM connection + force it to boot mode.

CBrosius, 2023-11-01:
Still not able to reproduce this. My ESP32 is always connected to the heatpump as yours. Updated flawless from 2023.10.0 to 2023.10.1 to 2023.10.2 to 2023.10.3 to 2023.10.5.

optimismus, 2023-11-01:
May be it has to do with my flashed version. I flashed the ESPs from cmd-ESPHOME on Windows 11. I will try to flash an ESP from HA.

buzz1976, 2023-11-02:
I have the same issue

INFO ESPHome 2023.10.5
INFO Reading configuration /config/esphome/luxtronik-v1-esp32.yaml...
INFO Starting log output from luxtronik-v1-esp32.local using esphome API
WARNING Can't connect to ESPHome API for luxtronik-v1-esp32.local: Error connecting to ('192.168.178.140', 6053): [Errno 111] Connect call failed ('192.168.178.140', 6053) (SocketAPIError)
INFO Trying to connect to luxtronik-v1-esp32.local in the background

buzz1976, 2023-11-04:
Hello,
i found the error! There is a double line in the yaml-file.
Please delete one line and it works

 - name: "WP_Status_Betriebszustand"
 - name: "WP_Status_Betriebszustand"

Regards Thorsten

CBrosius, 2023-11-04:
Hi Thorsten, good finding. In my local code the duplicate line is not there, but in the repo it was. (I already commited the fix)
@optimismus Does that fix your issue, too?

buzz1976, 2023-11-10:
Hello,
after the web server on the ESP32 is now running, I have another issue with receiving data from the heat pump. The state for all values shows only "NA." I have checked the heat pump with Putty and it's working. The command 1100 is also being sent via the ESP32 and receives data. However, these data are not processed by the parser. Is there anything known that could be causing this issue?
Regards Thorsten

CBrosius, 2023-11-10:
> The command 1100 is also being sent via the ESP32 and receives data.

How did you check that it receives data? Did you see the response in the ESP-Log?
Most of the time the data gets not processed, it is because of cabling-issues.

optimismus, 2023-11-11:
My ESP ist working with 2023.10.6 now.

optimismus, 2023-11-12:
My ESP is working with Firmware: 2023.10.6.
off topic: May be activate "discussion" in github for this repro.

Closed 2023-11-12.

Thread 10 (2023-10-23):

GPIO2 / GPIO4 are strapping pins

optimismus, 2023-10-23:
WARNING GPIO2 is a Strapping PIN and should be avoided.
    Attaching external pullup/down resistors to strapping pins can cause unexpected failures.
    See [Frequently Asked Questions — ESPHome](https://esphome.io/guides/faq.html#why-am-i-getting-a-warning-about-strapping-pins)
    WARNING GPIO4 is a Strapping PIN and should be avoided.
    Attaching external pullup/down resistors to strapping pins can cause unexpected failures.
    See [Frequently Asked Questions — ESPHome](https://esphome.io/guides/faq.html#why-am-i-getting-a-warning-about-strapping-pins)

optimismus, 2023-10-23:
I changed the pins to GPIO16 (RX) and GPIO17 (TX) and it works:
`# UART1
  rx_pin: GPIO16
  tx_pin: GPIO17`

inside the yaml.

optimismus, 2023-10-23:
I opened a pull request

Closed 2023-11-01.

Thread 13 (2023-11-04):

RX/TX pins for D1 mini

jensrossbach, 2023-11-04:
Is it correct to use pins D5 and D6 on D1 mini for RX/TX? Shouldn't it be the RX and TX pins (UART0) instead?

CBrosius, 2023-11-04:
> Is it correct to use pins D5 and D6 on D1 mini for RX/TX? Shouldn't it be the RX and TX pins (UART0) instead?

If I remember correct, I wanted to use UART0 for USB Debugging while connected to the heatpump at the same time. This was before I switched to ESPHome. I never tested other Pins, after the communication was working.

CBrosius, 2023-11-04:
https://forum.arduino.cc/t/wemos-d1-mini-pro-and-serial/857849

This describes what I mean.

jensrossbach, 2023-11-05:
As far as I understand, using pins D5 and D6 means software UART. From your tests, is the communication with the heat pump reliable enough with software UART?

CBrosius, 2023-11-05:
When I was using the D1Mini for the monitoring, I always have had read-errors here and there that resulted in wrong peak-values. Maybe this was related to SoftUART, but I don´t know for sure.
Since I switched to the ESP32 D1 Mini, this was never an issue again.

jensrossbach, 2023-11-05:
Ok, I will make some tests with different pins as soon as I have bought a serial cable.

By the way, have you ever tested the firmware without a heat pump connected? I made a quick test on a D1 mini without anything connected to the RS232 port and I get a boot loop (followed by a boot in safe mode) due to an exception during boot phase.

CBrosius, 2023-11-05:
Good question. I don´t think so. I have always had the RS232toTTL-Adapter connected. Not the heatpump, but the adapter.

cbrosius, 2025-03-10:
I will close this issue, as I did a rewrite of the component and like to start over without mixing old and new versions.

Closed 2025-03-10.

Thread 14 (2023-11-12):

Feature-Request: Set modes and temperatures

optimismus, 2023-11-12:
I would like to set "WP_Modus_Heizung", "WP_Modus_Warmwasser", "WP_Temp_Brauchwasser_Soll_Temperatur" and "WP_Temp_Heizkreis_Soll_Ruecklauftemperatur".
That would help to use photovoltaik engery or dynamic energy costs (e.g. Tibber prices) when they are cheap(er).

CBrosius, 2023-11-18:
Yes, that is the next step. But we have to send several commands with the right timing to achive this.

optimismus, 2023-11-18:
Thank you. We had a private discussion on this, but I thought github is the place the information should be.

BTW: You can use labels (here "enhancement") to flag issues.

BTW2: I would appreciate, if you enable discussion for this repro.

CBrosius, 2023-11-18:
Great idea, opened Discussion-Area directly. And thank you for your great documentation-additions.

CBrosius, 2023-11-25:
A few minutes ago I uploaded a new ESP32-Version in the WorkInProgress-branch with the first implementation of the Set-Possibility.
You are able to set Heizungsmode and Warmwassermode.

Please let me know how this is working for you.

optimismus, 2023-11-25:
Thank you very much for your work.
I tried both Heizungsmode and Warmwassermode, when the heatpump was doing "Brauchwasser". It worked for Warmwassermode, Heizungsmode is reset after a second:
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
To set heating on/off will be quite cool to use solar power or cheap engery costs (e.g. Tibber). But a more fine tuning possibility would be to set the SOLL-temperatures.

ohosch, 2025-02-14:
Is still someone working on this?
I am Using this great integration since around 2 Month. This Morning something got corrupt, so I could only get back by power-cycling the HeatPump. Unfortunately I did not capture the esp output. I think it got stuck in programming mode and could not get out of it. It looked like pressing e.g. "uart Exit ProgramMode" did not send any string to the HeatPump.
Is it somehow possible to get logs directly from the ESP?

cbrosius, 2025-02-16:
I still use it as it is, but have not done any further development.
For me, reading the values is enough, I don´t need to set modes or write anything to the heatpump.

cbrosius, 2025-03-24:
Hier mal ein Link zur Umfrage ob ich das Schreiben von Werten einbauen soll: https://github.com/cbrosius/luxtronik_v1/discussions/30

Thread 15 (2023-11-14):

"WP_Status_Betriebszustand" is always 1

optimismus, 2023-11-14:
After deleting the second "Betriebszustand" line the status seems to be always "1":
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

CBrosius, 2023-11-25:
Can you please check again with the new 'WorkInProgress"-branch version?
Maybe there were 2 WP_Status_Betriebszustand.
Seems that Homeassistant does not like the removal of values/channels of an existing device.
I had similar things happen, when I added buttons in the code and removed them again, later.
Inside of HomeAssistant the buttons remain, but do no longer work.

No sure how to reinitialize the ESPHome-Device in HomeAssistant without loosing the history.

cbrosius, 2025-03-10:
Like stated, you have to delete the component and create it new. Then the ghost-entries are fixed.

Closed 2025-03-10.

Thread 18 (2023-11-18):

WP_Temp_Mischkreis_1_Soll_Vorlauftemperatur is 0°C

optimismus, 2023-11-18:
The "Soll_Vorlauftemperatur" is always 0°C.

CBrosius, 2023-11-25:
Did you recheck that with the values in the heatpump via the Display (Service -> Informations -> Temperaturen -> MK1VL-Soll)
In my Heatpump this value is always 0°C, too.
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

optimismus, 2023-11-25:
Just checked it an you are absolutly right, sorry, didn't expected that. My setting is 0,0°C too.

Closed 2023-11-25.

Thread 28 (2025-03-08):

Config Ordner

approx3145, 2025-03-08:
Hallo

Kann keinen config/esphome Ordner finden

Es gibt nur einen esphome folder

cbrosius, 2025-03-08:
Ja, das ist der korrekte Ordner. Da einfach die luxtronik_v1_sensor.h mit reinlegen.
Allerdings musst Du beachten, daß die aktuellste ESPHome-Version keine CustomComponents mehr unterstützt.
Du brauchst also eine Version vor 2025 damit erfolgreich kompiliert werden kann.

Ab 2025 werden nur noch ExternalComponents unterstützt, das hab ich mir schonmal angesehen, konnte es aber auf die Schnelle nicht problemlos umprogrammieren. Da muss ich in Ruhe nochmal ran. Ist aber definitiv auf meiner ToDo-Liste.

Gruß,
Christian...

approx3145, 2025-03-10:
wie kann ich die serielle Verbindung kontrollieren? Sehe da keine Angaben?

[13:03:15][C][uart.arduino_esp32:151]: UART Bus 0:
[13:03:15][C][uart.arduino_esp32:152]:   TX Pin: GPIO17
[13:03:15][C][uart.arduino_esp32:153]:   RX Pin: GPIO16
[13:03:15][C][uart.arduino_esp32:155]:   RX Buffer Size: 256
[13:03:15][C][uart.arduino_esp32:157]:   Baud Rate: 57600 baud
[13:03:15][C][uart.arduino_esp32:158]:   Data Bits: 8
[13:03:15][C][uart.arduino_esp32:159]:   Parity: NONE
[13:03:15][C][uart.arduino_esp32:160]:   Stop bits: 1
[13:03:15][C][uptime.sensor:033]: Uptime Sensor 'Uptime Sensor'
[13:03:15][C][uptime.sensor:033]:   Device Class: 'duration'
[13:03:15][C][uptime.sensor:033]:   State Class: 'total_increasing'
[13:03:15][C][uptime.sensor:033]:   Unit of Measurement: 's'
[13:03:15][C][uptime.sensor:033]:   Accuracy Decimals: 0
[13:03:15][C][uptime.sensor:033]:   Icon: 'mdi:timer-outline'
[13:03:15][C][uptime.sensor:034]:   Type: Seconds
[13:03:15][C][status:034]: Status Binary Sensor 'luxtronik-v1-esp32'
[13:03:15][C][status:034]:   Device Class: 'connectivity'
[13:03:15][C][web_server:153]: Web Server:
[13:03:15][C][web_server:154]:   Address: 192.168.10.12:80
[13:03:15][C][mdns:116]: mDNS:
[13:03:15][C][mdns:117]:   Hostname: luxtronik-v1-esp32
[13:03:15][C][esphome.ota:073]: Over-The-Air updates:
[13:03:15][C][esphome.ota:074]:   Address: 192.168.10.12:3232
[13:03:15][C][esphome.ota:075]:   Version: 2
[13:03:15][C][safe_mode:018]: Safe Mode:
[13:03:15][C][safe_mode:020]:   Boot considered successful after 60 seconds
[13:03:15][C][safe_mode:021]:   Invoke after 10 boot attempts
[13:03:15][C][safe_mode:023]:   Remain in safe mode for 300 seconds
[13:03:15][C][api:140]: API Server:
[13:03:15][C][api:141]:   Address: 192.168.10.12:6053
[13:03:15][C][api:145]:   Using noise encryption: NO
[13:03:15][C][wifi_signal.sensor:010]: WiFi Signal 'WiFi Signal Sensor'
[13:03:15][C][wifi_signal.sensor:010]:   Device Class: 'signal_strength'
[13:03:15][C][wifi_signal.sensor:010]:   State Class: 'measurement'
[13:03:15][C][wifi_signal.sensor:010]:   Unit of Measurement: 'dBm'
[13:03:15][C][wifi_signal.sensor:010]:   Accuracy Decimals: 0
[13:03:15][D][sensor:094]: 'WiFi Signal Sensor': Sending state -42.00000 dBm with 0 decimals of accuracy

cbrosius, 2025-03-10:
die serielle Verbindung wird in der YAML konfiguriert.

```
uart:
  baud_rate: 57600
  rx_pin: GPIO16
  tx_pin: GPIO17
  # baud_rate (Required, int): The baud rate of the UART bus.
  # rx_pin (Optional, Pin): The pin to receive data on from the ESP’s perspective.
  # tx_pin (Optional, Pin): The pin to send data to from the ESP’s perspective.
  data_bits: 8
  #data_bits (Optional, int): The number of data bits used on the UART bus. Options: 5 to 8. Defaults to 8.
  #parity (Optional): The parity used on the UART bus. Options: NONE, EVEN, ODD. Defaults to NONE.
  parity: NONE
  #stop_bits (Optional, int): The number of stop bits to send. Options: 1, 2. Defaults to 1.
  stop_bits: 1
  # id (Optional, ID): Manually specify the ID for this UART hub if you need multiple UART hubs
  id: uart_bus
```

cbrosius, 2025-03-10:
Mit dem aktuellen Update wird keine luxtronik_v1_sensor.h mehr im config-Ordner benötigt.
ESPHOME hat mit Version 2025.2 die Verwendung von CustomComponents entfernt, wodurch eine Restrukturierung notwendig wurde. Die aktuelle Version von luxtronik_v1 ist jetzt eine ExternalComponent. Verwendung siehe angepasste .yaml Beispieldateien.

Closed 2025-03-10.

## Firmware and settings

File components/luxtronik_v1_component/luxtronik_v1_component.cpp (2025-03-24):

#include "esphome/core/log.h"
#include "luxtronik_v1_component.h"

namespace esphome {
namespace luxtronik_v1_component {

static const char *TAG = "luxtronik_v1_component.component";

void LuxtronikV1Component::setup() {
    ESP_LOGCONFIG(TAG, "Setting up Luxtronik V1 Component...");
    if (this->parent_ == nullptr) {
        ESP_LOGE(TAG, "UART parent not set!");
        this->mark_failed();
        return;
    }

    // Request initial values immediately after setup
    this->parent_->write_str("1100\r\n");
}

void LuxtronikV1Component::loop() {
    if (this->parent_ == nullptr) {
        ESP_LOGW(TAG, "Cannot loop - UART parent not set");
        return;
    }
    
    while (this->parent_->available()) {
        uint8_t c;
        if (!this->parent_->read_byte(&c)) {
            continue;
        }
        
        if (c == ASCII_CR || c == ASCII_LF) {
            if (this->read_pos_ > 0) {
                this->read_buffer_[this->read_pos_] = '\0';
                ESP_LOGD(TAG, "Received: %s", this->read_buffer_);
                parse_message_(this->read_buffer_);
                this->read_pos_ = 0;
            }
        } else {
            this->read_buffer_[this->read_pos_++] = c;
            if (this->read_pos_ >= READ_BUFFER_LENGTH) {
                this->read_pos_ = 0;
            }
        }
    }
}

void LuxtronikV1Component::update() {
    ESP_LOGD(TAG, "Polling Luxtronik V1 Component...");
    if (this->parent_ != nullptr) {
        this->parent_->write_str("1100\r\n");
    }
}

// Helper function for deferred publishing
void LuxtronikV1Component::publish_state_deferred_(sensor::Sensor* sensor, float value, const char* type, const char* name) {
    this->defer([this, sensor, value, type, name]() {
        sensor->publish_state(value);
        ESP_LOGV(TAG, "%s %s: %.1f", type, name, value);
    });
}

void LuxtronikV1Component::parse_message_(const char* message) {
    std::string msg(message);
    
    if (msg.empty() || msg.length() < 4) {
        return;
    }

    // Use substring comparison for better performance
    std::string prefix = msg.substr(0, 4);
    
    if (prefix == "1100") {
        this->defer([this, msg]() {
            parse_temperatur_message_(msg.c_str());
        });
    } else if (prefix == "1200") {
        this->defer([this, msg]() {
            parse_input_message_(msg.c_str());
        });
    } else if (prefix == "1300") {
        this->defer([this, msg]() {
            parse_output_message_(msg.c_str());
        });
    } else if (prefix == "3405") {
        this->defer([this, msg]() {
            parse_modus_heizung_message_(msg.c_str());
        });
    } else if (prefix == "3505") {
        this->defer([this, msg]() {
            parse_modus_warmwasser_message_(msg.c_str());
        });
    } else if (prefix == "1700") {
        this->defer([this, msg]() {
            parse_status_message_(msg.c_str());
        });
    } else if (prefix == "1500") {
        this->defer([this, msg]() {
            parse_error_message_(msg.c_str());
        });
    } else if (prefix == "1450") {
        this->defer([this, msg]() {
            parse_operatinghours_message_(msg.c_str());
        });
    }
}

void LuxtronikV1Component::parse_temperatur_message_(const char* message) {
    std::string msg(message);
    std::vector<std::string> values;
    size_t start = 5;  // Skip "1100;"
    size_t end = 0;
    
    // Split message into vector for faster processing
    while ((end = msg.find(';', start)) != std::string::npos) {
        values.push_back(msg.substr(start, end - start));
        start = end + 1;
    }
    
    if (start < msg.length()) {
        values.push_back(msg.substr(start));
    }
    
    if (values.size() < 2) return;  // At least count and one value needed
    
    size_t idx = 1;  // Skip count
    auto publish_temp = [this](sensor::Sensor* sensor, const std::string& value, const char* name) {
        if (sensor != nullptr) {
            float temp = get_float_temp_(value);
            publish_state_deferred_(sensor, temp, "Temperatur", name);
        }
    };

    // Process all temperature sensors
    if (idx < values.size()) publish_temp(temperatur_vorlauf_, values[idx++], "Vorlauf");
    if (idx < values.size()) publish_temp(temperatur_ruecklauf_, values[idx++], "Rücklauf");
    if (idx < values.size()) publish_temp(temperatur_ruecklauf_soll_, values[idx++], "Rücklauf Soll");
    if (idx < values.size()) publish_temp(temperatur_heissgas_, values[idx++], "Heissgas");
    if (idx < values.size()) publish_temp(temperatur_aussen_, values[idx++], "Aussen");
    if (idx < values.size()) publish_temp(temperatur_brauchwasser_, values[idx++], "Brauchwasser");
    if (idx < values.size()) publish_temp(temperatur_brauchwasser_soll_, values[idx++], "Brauchwasser Soll");
    if (idx < values.size()) publish_temp(temperatur_waermequelle_eingang_, values[idx++], "Wärmequelle Eingang");
    if (idx < values.size()) publish_temp(temperatur_kaeltekreis_, values[idx++], "Kältekreis");
    if (idx < values.size()) publish_temp(temperatur_mischkreis1_vorlauf_, values[idx++], "Mischkreis1 Vorlauf");
    if (idx < values.size()) publish_temp(temperatur_mischkreis1_vorlauf_soll_, values[idx++], "Mischkreis1 Vorlauf Soll");
    if (idx < values.size()) publish_temp(temperatur_raumstation_, values[idx++], "Raumstation");

    // Request input values after temperature values are parsed
    this->parent_->write_str("1200\r\n");
}
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

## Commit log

2023-08-20 add Wifi-Information as Text-Sensor
2023-08-25 add ESP32 Example
2023-08-27 add reading of heatpump modus
2023-08-30 add missing attributes to luxtronik-v1-esp32.yaml
2023-09-23 update to readme an esp32.yaml
2023-09-24 port esp32 changes to D1Mini
2023-10-23 some minor stuff
    - rename d1mini-yaml with no underscores
    - put esp32 GPIOs to 16 and 17
2023-11-01 add softwareversion to sensor-output
2023-11-04 remove duplicate 'WP_Status_Betriebszustand' in ESP32-YAML
2023-11-18 serial cable enhancements
2023-11-18 Serial cable
    More info for serial cable
2023-11-18 insert db9-solderless.jpg
2023-11-18 add fritzing files
    [luxtronik-esphome.fzz]
2023-11-18 insert fritzing jpg into readme
2025-03-11 add more sensors
2025-03-24 add operatinghours sensors
